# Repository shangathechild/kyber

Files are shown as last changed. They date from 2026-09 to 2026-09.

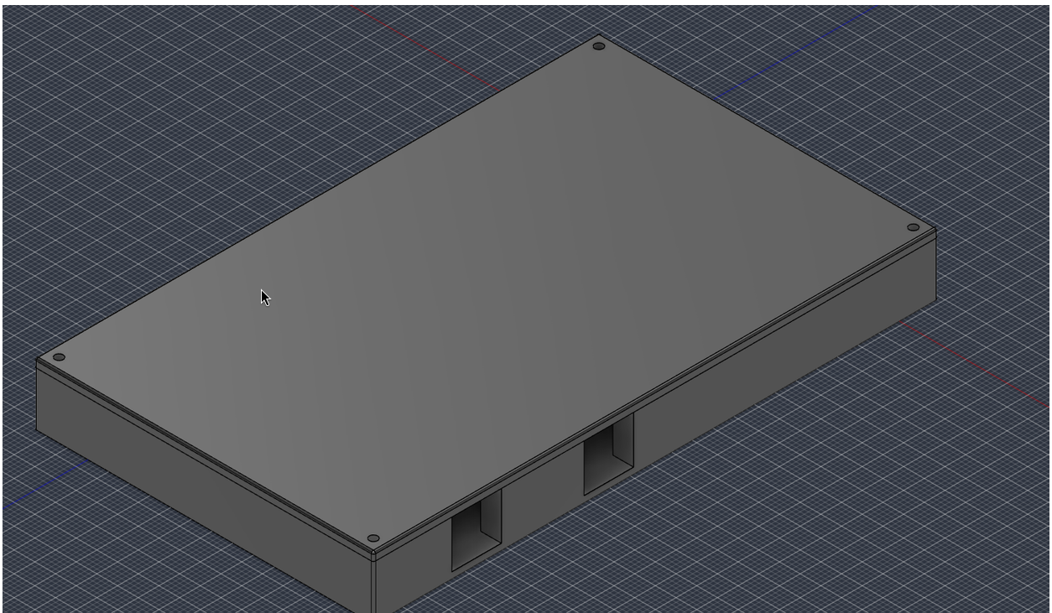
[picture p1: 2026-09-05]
screenshots/cad2.png

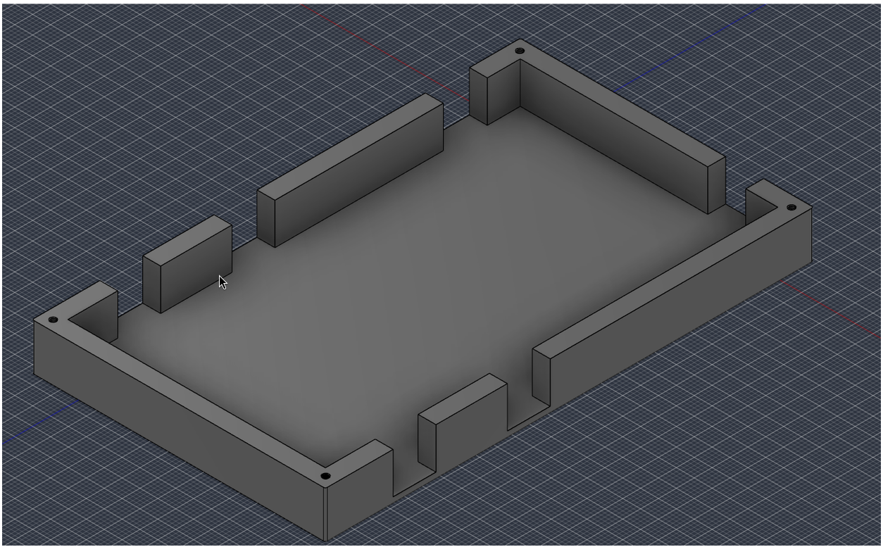
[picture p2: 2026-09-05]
screenshots/cad1.png

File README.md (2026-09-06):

# Kyber
An argb controller for Personal computers
I made this as my JRGB pins on my motherboard doesnt work properly. It could also be modified to support a greater number of ARGB headers.

### Features:
- It has 4 ARGB headers
- It has 1 4 pin molex power connector for a Peripheral connector which connects to the PSU

## PCB:
### Schematic:
schematic

### PCB:


## CAD
cad1
cad2

## Important notes:
- It takes up 15mm of width behind your computer
- You have to bend the Bulk capacitors legs to make it fit

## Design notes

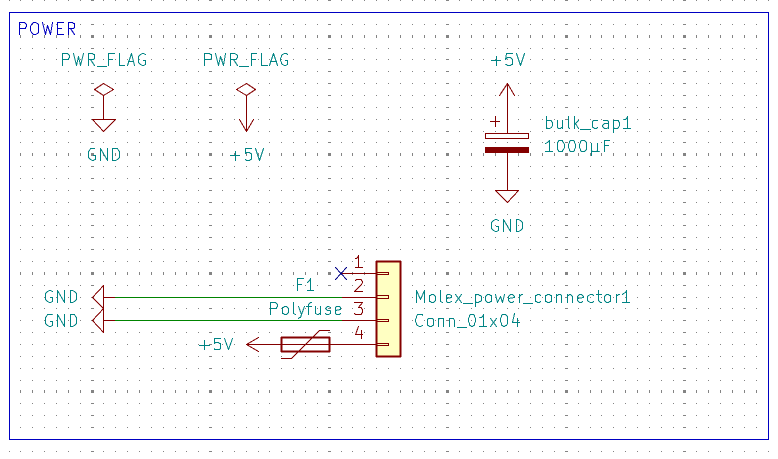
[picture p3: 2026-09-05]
screenshots/schematic4.png

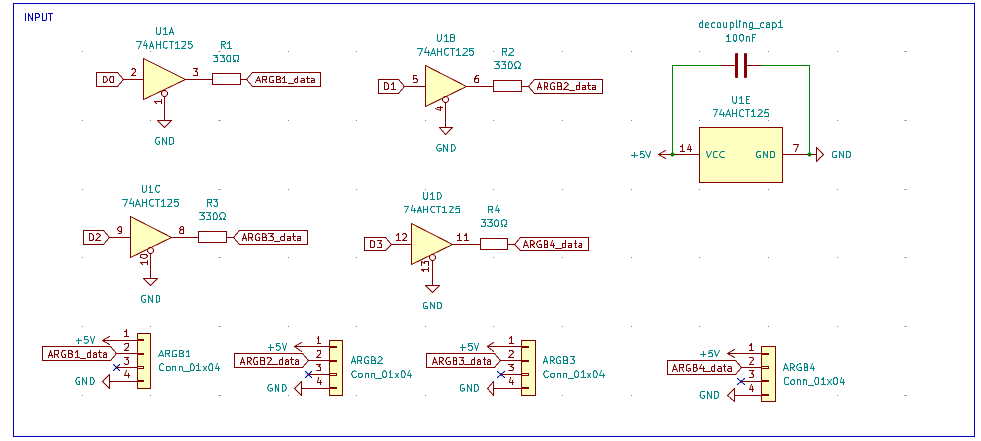
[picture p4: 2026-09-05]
screenshots/schematic3.png

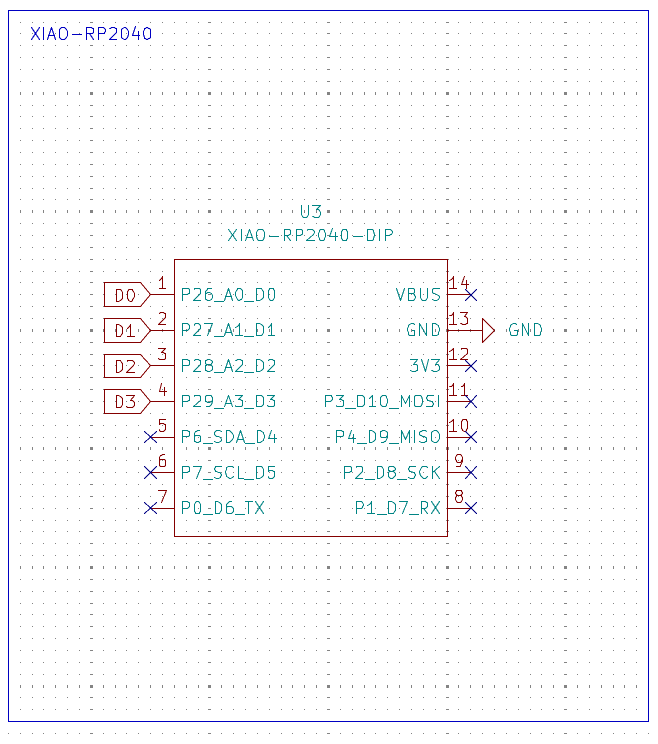
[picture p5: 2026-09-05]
screenshots/schematic2.png

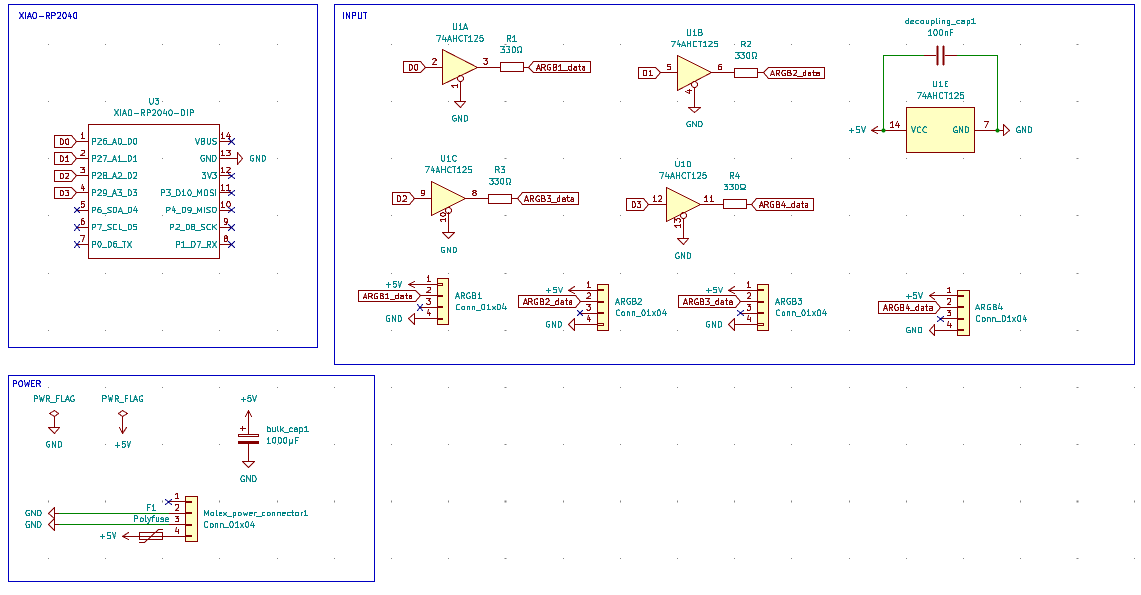
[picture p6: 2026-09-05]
screenshots/schematic1.png

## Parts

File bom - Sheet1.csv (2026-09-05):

Item Name | Qty | Price (total) (USD) | Item link
XIAO RP2040 | 1 | 6.74 | https://sharvielectronics.com/product/xiao-rp2040-supports-arduino-micropython-and-circuitpython-seeed-studio/
Logic buffer | 2 | 2.06 | https://www.lioncircuits.com/parts/SN74AHCT125N
ARGB header | 5 | 0.21 | https://sharvielectronics.com/product/4x1-4pin-male-right-angle-berg-header-connector-6mm-2-54mm-pitch/
Series resistor | 10 | 0.048 | https://sharvielectronics.com/product/330-ohm-1-4-watt-resistor-5-tolerance/
Buffer decoupling capacitor | 1 | 0.05 | https://sharvielectronics.com/product/100nf-100v-0-1uf-104-polyester-box-capacitor-5mm-pitch/
Bulk capacitor | 3 | 0.3 | https://sharvielectronics.com/product/1000uf-10v-electrolytic-capacitor-105c-10x16mm-elite/
Peripheral molex pin | 1 | 0 | https://robu.in/product/5-08-aw-5-08mm-4-pin-wafer-male-connector-through-hole-right-angle-molex-compatible/ | I will buy this myself as robu needs a minimum order value of 80
Polyfuse | 1 | 0.13 | https://sharvielectronics.com/product/rhef100-30v-1a-pptc-resettable-fuse-polyswitch-tyco-raychem/
M2x15mm Mounting Screws | 5 | 0.2 | https://sharvielectronics.com/product/m2x15mm-ch-head-mounting-screw-stainless-steel/
PCB | 5 | 16.18 | lioncircuits.com
Shipping for 3d printing | 1 | 1
Shipping for Lion circuits |  | 1.06
Total Price (USD): | $27.98

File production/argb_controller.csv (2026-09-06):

Reference | Qty | Value | DNP | Exclude from BOM | Exclude from Board | Exclude from Simulation | Exclude from Position Files | Footprint | Datasheet
ARGB1,ARGB2,ARGB3,ARGB4 | 4 | Conn_01x04 |  |  |  |  | ${EXCLUDE_FROM_POS_FILES} | Connector_PinHeader_2.54mm:PinHeader_1x04_P2.54mm_Horizontal
bulk_cap1 | 1 | 1000µF |  |  |  |  | ${EXCLUDE_FROM_POS_FILES} | Capacitor_THT:CP_Radial_D10.0mm_P5.00mm
decoupling_cap1 | 1 | 100nF |  |  |  |  | ${EXCLUDE_FROM_POS_FILES} | Capacitor_THT:C_Rect_L7.2mm_W2.5mm_P5.00mm
F1 | 1 | Polyfuse |  |  |  |  | ${EXCLUDE_FROM_POS_FILES} | footprints:FUS_RHEF100_TYCO_TYC
Molex_power_connector1 | 1 | Conn_01x04 |  |  |  |  | ${EXCLUDE_FROM_POS_FILES} | personal:PWR_Molex_4pin_P5.08mm_Horizontal
R1,R2,R3,R4 | 4 | 330Ω |  |  |  |  | ${EXCLUDE_FROM_POS_FILES} | Resistor_THT:R_Axial_DIN0207_L6.3mm_D2.5mm_P10.16mm_Horizontal
U1 | 1 | 74AHCT125 |  |  |  |  | ${EXCLUDE_FROM_POS_FILES} | Package_DIP:DIP-14_W7.62mm_LongPads | https://www.ti.com/lit/ds/symlink/sn74ahct125.pdf
U3 | 1 | XIAO-RP2040-DIP |  |  |  |  | ${EXCLUDE_FROM_POS_FILES} | Seeed_Studio_XIAO_Series:XIAO-RP2040-DIP

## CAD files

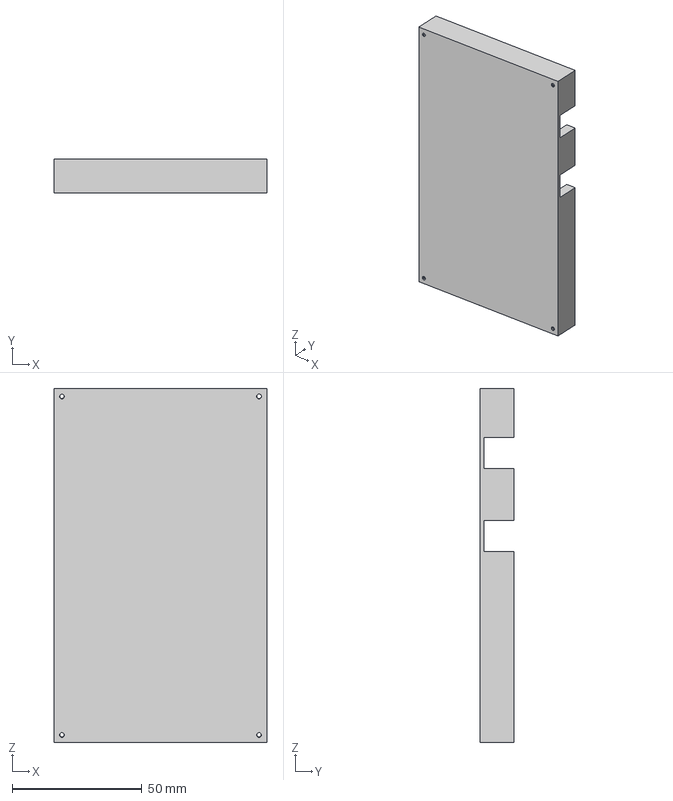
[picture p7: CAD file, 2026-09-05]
cad/Kyber-bottom.stp
82.0 x 13.0 x 136.5 mm

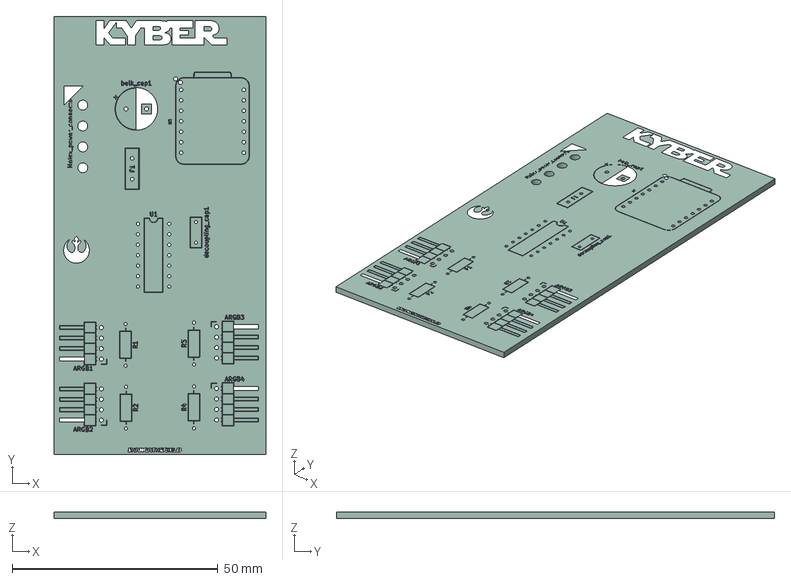
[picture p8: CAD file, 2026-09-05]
production/argb_controller.step
51.5 x 106.5 x 1.58 mm
argb_controller-unsaved-export-LwXrL3_silkscreen
argb_controller-unsaved-export-LwXrL3_PCB

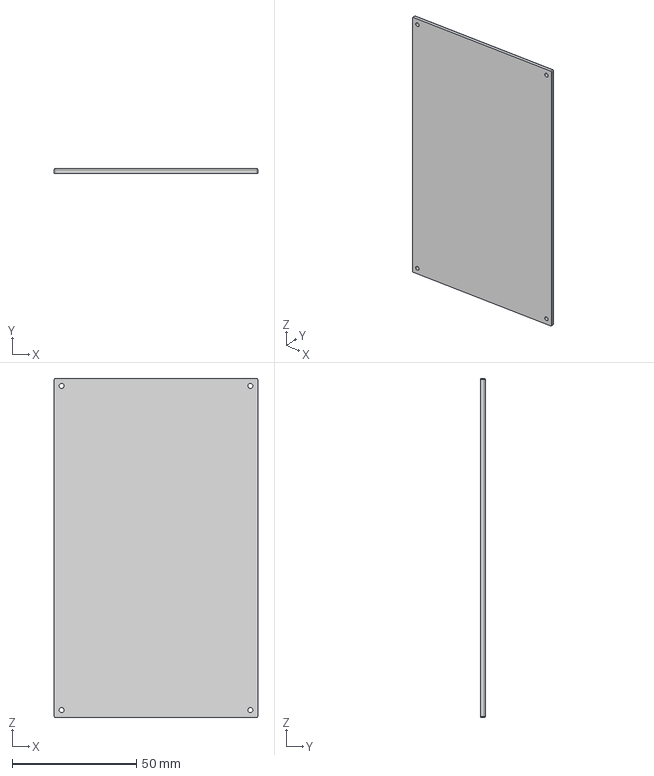
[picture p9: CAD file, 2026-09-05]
cad/Kyber-top.stp
82.0 x 2.00 x 136.5 mm

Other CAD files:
production/Kyber-top.stl
production/Kyber-bottom.stl

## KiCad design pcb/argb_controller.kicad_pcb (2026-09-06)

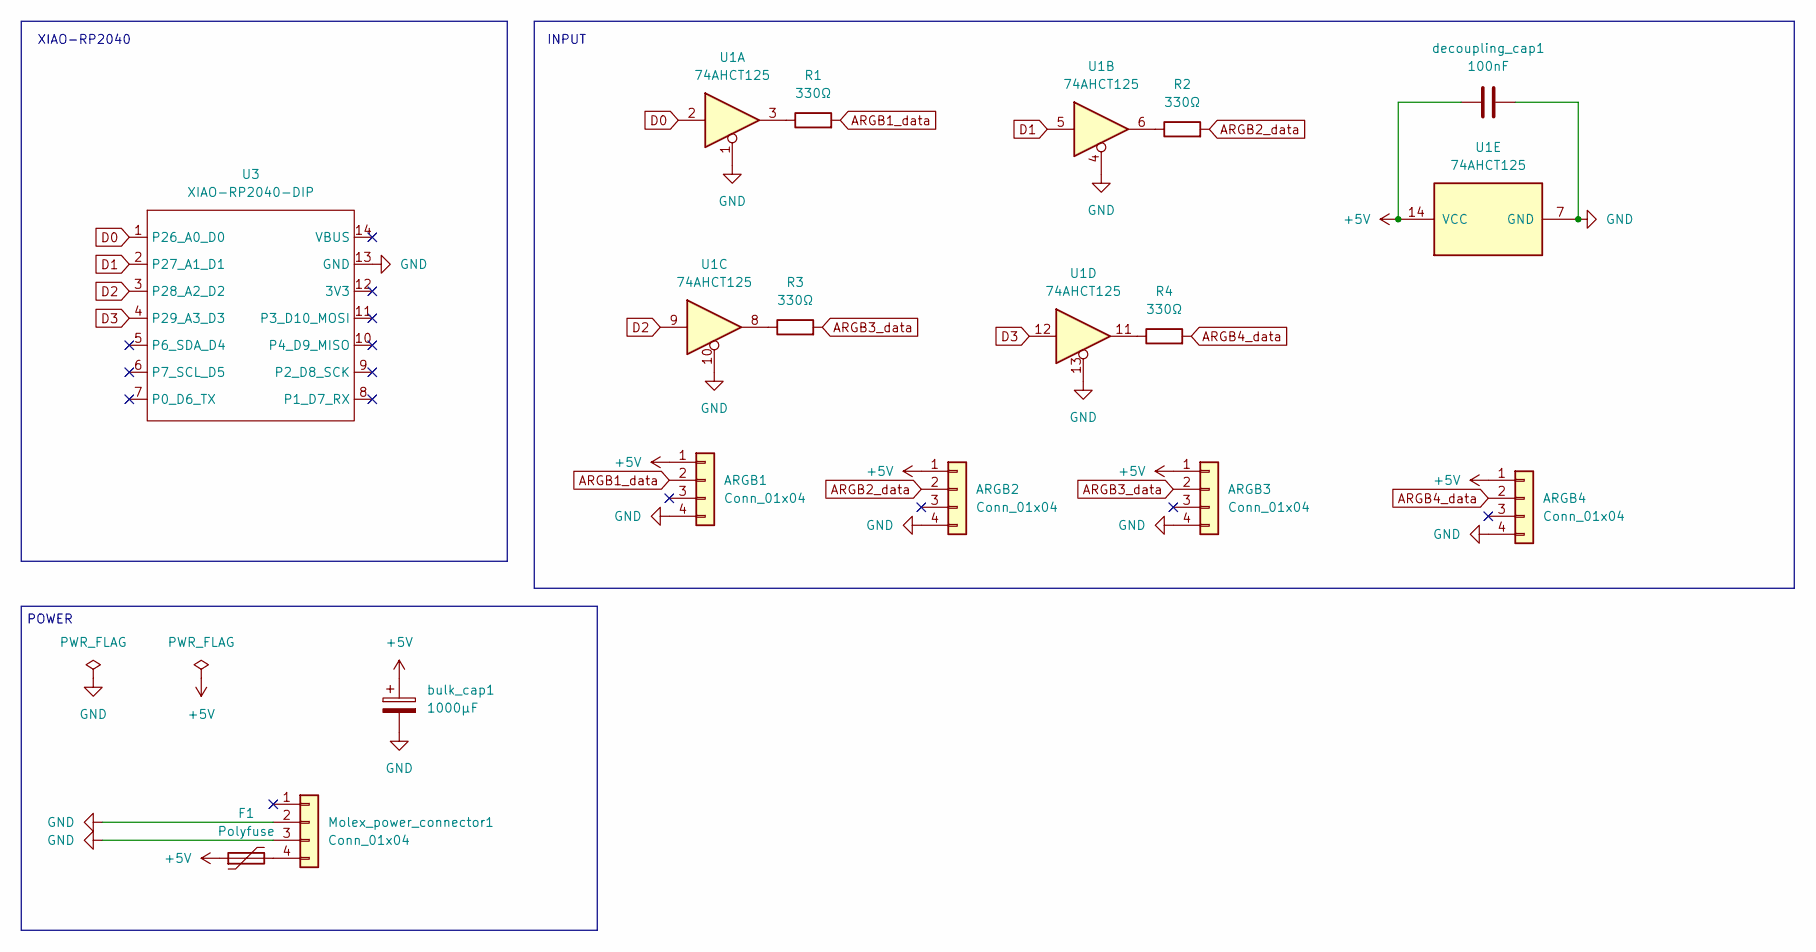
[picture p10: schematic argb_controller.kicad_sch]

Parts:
ARGB1, ARGB2, ARGB3, ARGB4: Conn_01x04; PinHeader_1x04_P2.54mm_Horizontal
F1: Polyfuse; FUS_RHEF100_TYCO_TYC
Molex_power_connector1: Conn_01x04; PWR_Molex_4pin_P5.08mm_Horizontal
R1, R2, R3, R4: 330Ω; R_Axial_DIN0207_L6.3mm_D2.5mm_P10.16mm_Horizontal
U1: 74AHCT125; DIP-14_W7.62mm_LongPads
U3: XIAO-RP2040-DIP
bulk_cap1: 1000µF; CP_Radial_D10.0mm_P5.00mm
decoupling_cap1: 100nF; C_Rect_L7.2mm_W2.5mm_P5.00mm

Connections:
+5V: ARGB1.1, ARGB2.1, ARGB3.1, ARGB4.1, F1.1, U1.14 (VCC), bulk_cap1.1, decoupling_cap1.1
ARGB1_data: ARGB1.2, R1.2
ARGB2_data: ARGB2.2, R2.2
ARGB3_data: ARGB3.2, R3.2
ARGB4_data: ARGB4.2, R4.2
D0: U1.2, U3.1 (P26_A0_D0)
D1: U1.5, U3.2 (P27_A1_D1)
D2: U1.9, U3.3 (P28_A2_D2)
D3: U1.12, U3.4 (P29_A3_D3)
GND: ARGB1.4, ARGB2.4, ARGB3.4, ARGB4.4, Molex_power_connector1.2, Molex_power_connector1.3, U1.1, U1.4, U1.7 (GND), U1.10, U1.13, U3.13 (GND), bulk_cap1.2, decoupling_cap1.2
unnamed: F1.2, Molex_power_connector1.4
unnamed: R1.1, U1.3
unnamed: R2.1, U1.6
unnamed: R3.1, U1.8
unnamed: R4.1, U1.11

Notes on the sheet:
INPUT
XIAO-RP2040
POWER

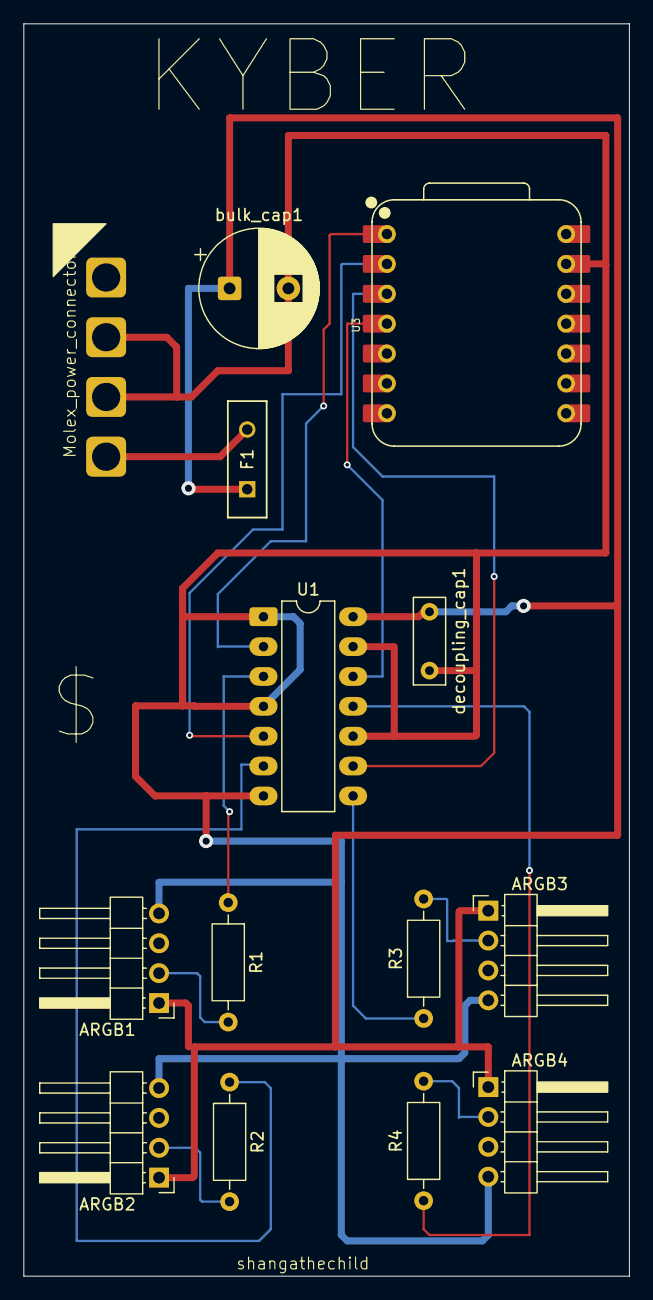
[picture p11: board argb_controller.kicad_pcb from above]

Board: 2 copper layers, 51.5 x 106.5 mm, 14 parts (0 on the bottom side), 15 nets.

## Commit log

2026-09-05 Update README with project details and images
    Added detailed features, PCB, and CAD information.
2026-09-05 Add PCB image to README
2026-09-06 Update PCB and add CAD images in README
    Replaced old PCB image with a new one and added CAD images.
